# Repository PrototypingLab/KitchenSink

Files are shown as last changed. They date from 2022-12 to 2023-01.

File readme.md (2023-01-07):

# Kitchen Sink

## Kitchen Sink Mini - ESP32-WROOM

### Future Ideas
- Add transistor LED circuit for TX / RX
- Add TVS diode protection circuit

### v1.3 Changelog
- Fixed series capacitor issue on voltage regulators
- Updated power netclass to include RTC battery
- Updated date on silkscreen, added version number

### v1.2 Changelog
- Added solder bridges for selecting IO0 and EN from buttons or (USB-Serial IC and programming header)
- Added 3 additional LEDs on pins designated for shift out
- Moved module closer to edge of board, with space on either side
- Added cutout around module antenna on bottom and top layer
- Added netclass for power traces to be 15 mil
- Updated power traces to 15 mil
- Updated via drill size to be 3 mm
- Updated date on bottom silkscreen

### v1.1 Changelog
- Updated programming header

---------------------

## "Our Programmer"

### v1.1 Changelog
- Added netclass for power traces to be 15 mil
- Updated power traces to 15 mil
- Updated via drill size to be 3 mm
- Updated date on bottom silkscreen

---------------------

## Design Settings
- Trace width: 10 mil
- Power trace width: 15 mil
- Via drill: 3 mm **note units (~ 11.81102 mil)**
- Via annular ring: 10 mil

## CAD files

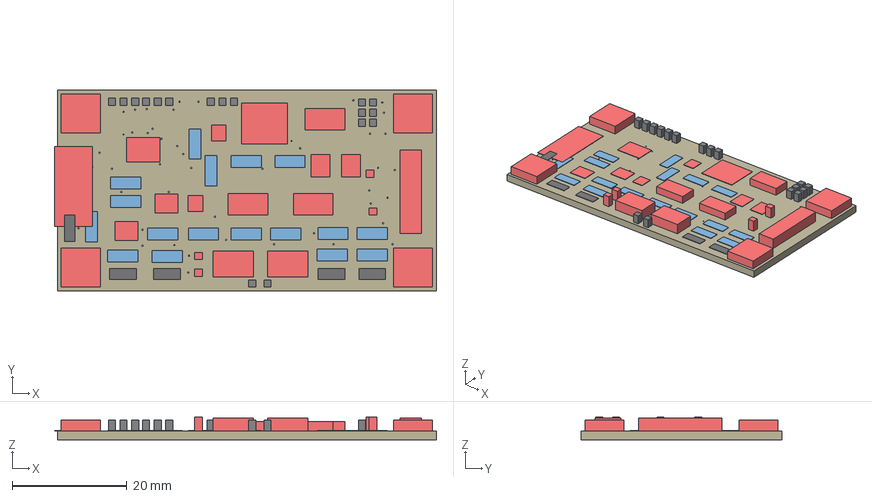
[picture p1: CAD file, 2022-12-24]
our-programmer/esp32_programmer.step
66.7 x 35.0 x 3.99 mm
Board
MOUNT-HOLE3.0 x 4
1206.LED x 5
MOMENTARY-SWITCH-SPST-SMD-5.2MM x 2
TEST-POINT3X5 x 17
CP2102N-A02-GQFN24QFN24_CP2102N_SIL-M
MMBT3904_R1 x 2
AP2111H-3.3TRG1SOT-223_DIO-M
10103592-0001LF-EK
1X03_LONGPADS x 3
1X06_LONGPADS
JUMPER-SMT_2_NC_PASTE_SILK x 4
NPN: BC817 x 4

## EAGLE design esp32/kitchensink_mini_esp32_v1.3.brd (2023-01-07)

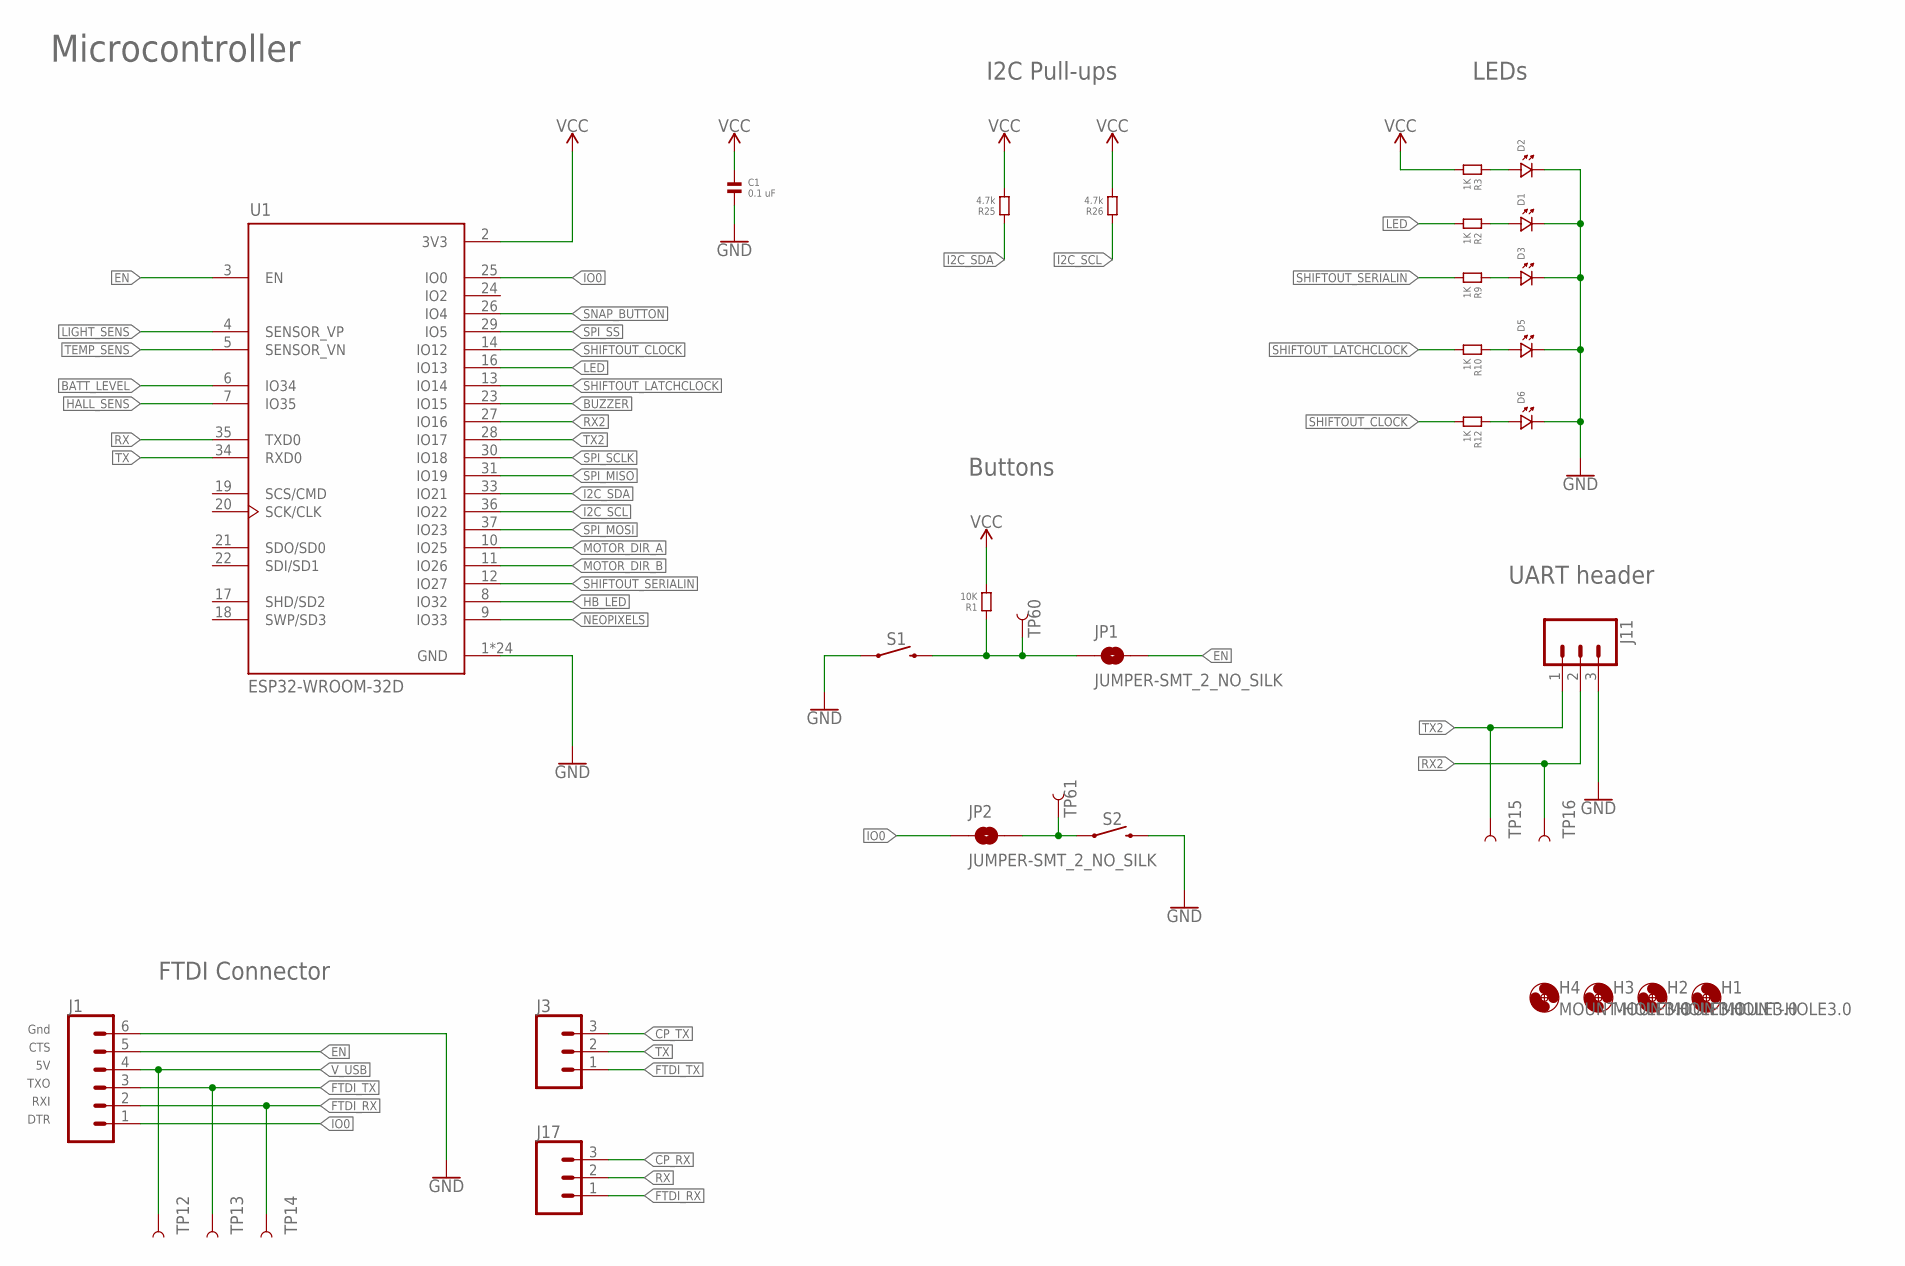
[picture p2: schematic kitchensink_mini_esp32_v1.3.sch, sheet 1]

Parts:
C1: 0.1 uF; 1206
D1, D2, D3, D5, D6: LED.1206; 1206.LED
H1, H2, H3, H4: MOUNT-HOLE3.0; 3,0
J1: CONN_06; 1X06-SMD_RA_MALE_NO_HOLES
J3, J17: CONN_03LONGPADS; 1X03_LONGPADS
J11: CONN_03SMD_RA_MALE; 1X03_SMD_RA_MALE
JP1, JP2: JUMPER-SMT_2_NO_SILK; SMT-JUMPER_2_NO_SILK
R1: 10K; 1206
R2, R3, R9, R10, R12: 1K; 1206
R25, R26: 4.7k; 1206
S1, S2: MOMENTARY-SWITCH-SPST-SMD-5.2MM; TACTILE_SWITCH_SMD_5.2MM
TP12, TP13, TP14, TP15, TP16, TP60, TP61: TEST-POINT3X5; PAD.03X.05
U1: ESP32-WROOM-32D; MODULE_ESP32-WROOM-32D

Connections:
BATT_LEVEL: U1.6 (IO34)
BUZZER: U1.23 (IO15); also elsewhere on the board
CP_RX: J17.3; also elsewhere on the board
CP_TX: J3.3; also elsewhere on the board
EN: J1.5, JP1.2, U1.3 (EN); also elsewhere on the board
FTDI_RX: J1.2, J17.1, TP14.P$1
FTDI_TX: J1.3, J3.1, TP13.P$1
GND: D1.P$2 (2), D2.P$2 (2), D3.P$2 (2), D5.P$2 (2), D6.P$2 (2), J1.6, J11.3, S1.1, U1.1 (GND), U1.15 (GND), U1.38 (GND), U1.39_1 (GND), U1.39_2 (GND), U1.39_3 (GND), U1.39_4 (GND), U1.39_5 (GND), U1.39_6 (GND), U1.39_7 (GND), U1.39_8 (GND), U1.39_9 (GND), U1.39_10 (GND), U1.39_11 (GND), U1.39_12 (GND), U1.39_13 (GND), U1.39_14 (GND), U1.39_15 (GND), U1.39_16 (GND), U1.39_17 (GND), U1.39_18 (GND), U1.39_19 (GND), U1.39_20 (GND), U1.39_21 (GND); also elsewhere on the board
HALL_SENS: U1.7 (IO35)
HB_LED: U1.8 (IO32)
I2C_SCL: R26.1, U1.36 (IO22); also elsewhere on the board
I2C_SDA: R25.1, U1.33 (IO21); also elsewhere on the board
IO0: J1.1, JP2.1, U1.25 (IO0); also elsewhere on the board
LED: R2.2, U1.16 (IO13)
LIGHT_SENS: U1.4 (SENSOR_VP); also elsewhere on the board
MOTOR_DIR_A: U1.10 (IO25)
MOTOR_DIR_B: U1.11 (IO26)
unnamed: C1.2, S2.3 (2)
unnamed: D3.P$1 (1), R9.1
unnamed: D1.P$1 (1), R2.1
unnamed: D5.P$1 (1), R10.1
unnamed: D2.P$1 (1), R3.1
unnamed: D6.P$1 (1), R12.1
NEOPIXELS: U1.9 (IO33); also elsewhere on the board
PRE_EN: JP1.1, R1.1, S1.3 (2), TP60.P$1
PRE_IO0: JP2.2, S2.1, TP61.P$1
RX: J17.2, U1.35 (TXD0)
RX2: J11.2, TP16.P$1, U1.27 (IO16)
SHIFTOUT_CLOCK: R12.2, U1.14 (IO12)
SHIFTOUT_LATCHCLOCK: R10.2, U1.13 (IO14)
SHIFTOUT_SERIALIN: R9.2, U1.12 (IO27)
SNAP_BUTTON: U1.26 (IO4); also elsewhere on the board
SPI_MISO: U1.31 (IO19); also elsewhere on the board
SPI_MOSI: U1.37 (IO23); also elsewhere on the board
SPI_SCLK: U1.30 (IO18); also elsewhere on the board
SPI_SS: U1.29 (IO5); also elsewhere on the board
TEMP_SENS: U1.5 (SENSOR_VN); also elsewhere on the board
TX: J3.2, U1.34 (RXD0)
TX2: J11.1, TP15.P$1, U1.28 (IO17)
VCC: R1.2, R3.2, R25.2, R26.2, U1.2 (3V3); also elsewhere on the board
V_USB: J1.4, TP12.P$1; also elsewhere on the board

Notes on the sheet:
Microcontroller
FTDI Connector
I2C Pull-ups
UART header
LEDs
Buttons
Gnd
CTS
TXO
RXI
DTR

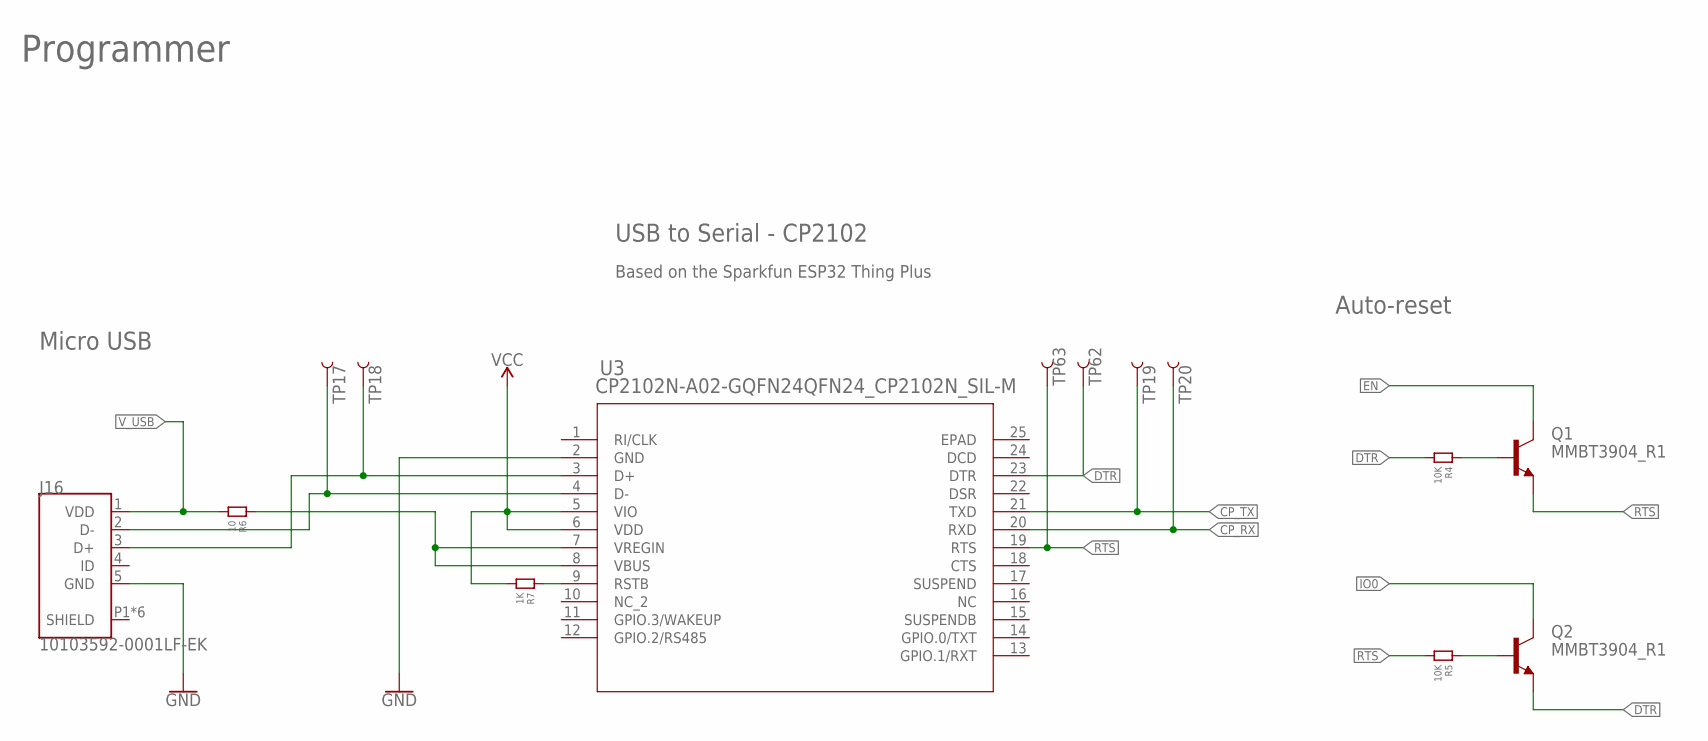
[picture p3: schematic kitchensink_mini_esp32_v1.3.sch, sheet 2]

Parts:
J16: 10103592-0001LF-EK; AMPHENOL_10103592-0001LF
Q1, Q2: MMBT3904_R1; SOT23
R4, R5: 10K; 1206
R6: 10; 1206
R7: 1K; 1206
TP17, TP18, TP19, TP20, TP62, TP63: TEST-POINT3X5; PAD.03X.05
U3: CP2102N-A02-GQFN24QFN24_CP2102N_SIL-M; QFN24_CP2102N_SIL-M

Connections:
CP_RX: TP20.P$1, U3.20 (RXD); also elsewhere on the board
CP_TX: TP19.P$1, U3.21 (TXD); also elsewhere on the board
DTR: Q2.2 (E), R4.2, TP62.P$1, U3.23 (DTR)
EN: Q1.3 (C); also elsewhere on the board
GND: J16.5 (GND), U3.2 (GND); also elsewhere on the board
IO0: Q2.3 (C); also elsewhere on the board
unnamed: R6.1, U3.7 (VREGIN), U3.8 (VBUS)
unnamed: J16.3 (D+), TP18.P$1, U3.3 (D+)
unnamed: J16.2 (D-), TP17.P$1, U3.4 (D-)
unnamed: Q1.1 (B), R4.1
unnamed: Q2.1 (B), R5.1
unnamed: R7.1, U3.9 (RSTB)
RTS: Q1.2 (E), R5.2, TP63.P$1, U3.19 (RTS)
SHIELD: J16.P1 (SHIELD), J16.P2 (SHIELD), J16.P3 (SHIELD), J16.P4 (SHIELD), J16.P5 (SHIELD), J16.P6 (SHIELD)
VCC: R7.2, U3.5 (VIO), U3.6 (VDD); also elsewhere on the board
V_USB: J16.1 (VDD), R6.2; also elsewhere on the board

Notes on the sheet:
Programmer
USB to Serial - CP2102
Auto-reset
Micro USB
Based on the Sparkfun ESP32 Thing Plus

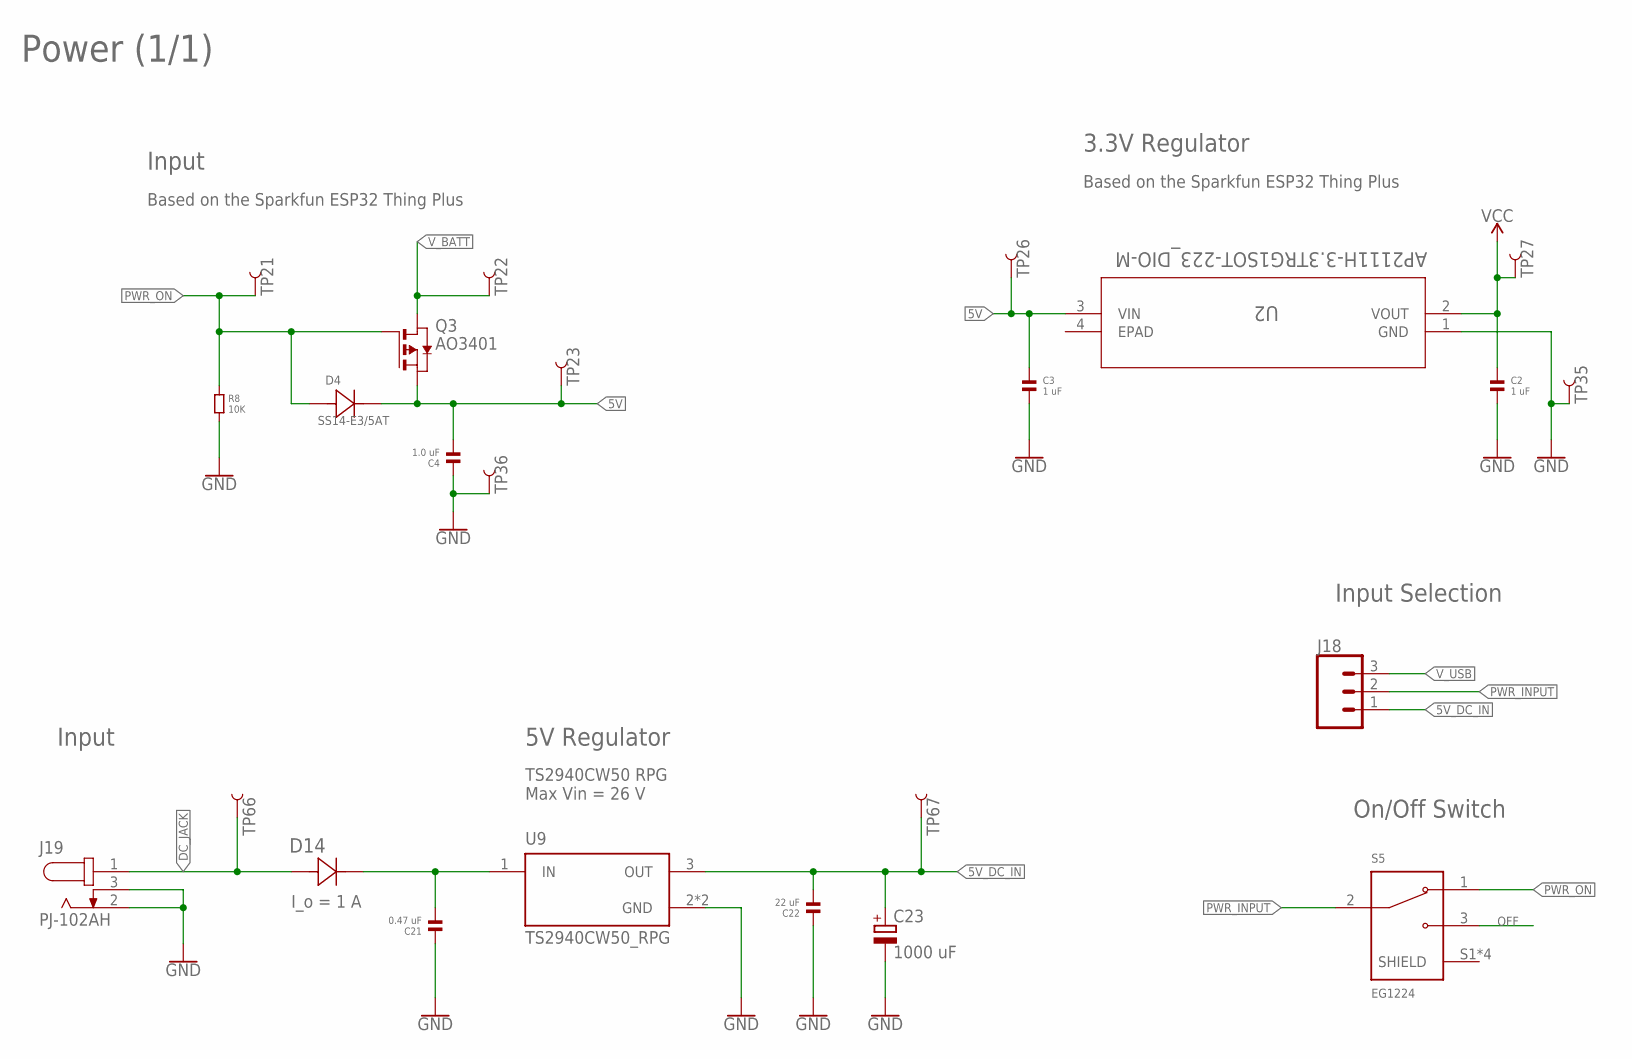
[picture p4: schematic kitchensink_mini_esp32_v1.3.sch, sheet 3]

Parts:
C2, C3: 1 uF; 1206
C4: 1.0 uF; 1206
C21: 0.47 uF; 1206
C22: 22 uF; 1206
C23: 1000 uF; 140CLH-1010
D4: SS14-E3/5AT; DIODE_DO214AC
D14: RS1BB-13-FSMA_DIO-M; SMA_DIO-M
J18: CONN_03; 1X03
J19: PJ-102AH; CUI_PJ-102AH
Q3: AO3401; SOT23
R8: 10K; 1206
S5: EG1224; SW_EG1224
TP21, TP22, TP23, TP26, TP27, TP35, TP36, TP66, TP67: TEST-POINT3X5; PAD.03X.05
U2: AP2111H-3.3TRG1SOT-223_DIO-M; SOT-223_DIO-M
U9: TS2940CW50_RPG; VREG_TS2940CW50_RPG

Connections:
5V: C3.1, C4.2, D4.1, Q3.2 (S), TP23.P$1, TP26.P$1, U2.3 (VIN); also elsewhere on the board
5V_DC_IN: C22.2, C23.+, J18.1, TP67.P$1, U9.3 (OUT)
DC_JACK: D14.2, J19.1, TP66.P$1
GND: C2.2, C3.2, C4.1, C21.1, C22.1, C23.-, J19.2, J19.3, R8.2, TP35.P$1, TP36.P$1, U2.1 (GND), U9.2 (GND), U9.4 (GND); also elsewhere on the board
unnamed: C21.2, D14.1, U9.1 (IN)
OFF: S5.3
PWR_INPUT: J18.2, S5.2
PWR_ON: D4.2, Q3.1 (G), R8.1, S5.1, TP21.P$1
VCC: C2.1, TP27.P$1, U2.2 (VOUT); also elsewhere on the board
V_BATT: Q3.3 (D), TP22.P$1
V_USB: J18.3; also elsewhere on the board

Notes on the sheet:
Power (1/1)
Input
Based on the Sparkfun ESP32 Thing Plus
3.3V Regulator
Input Selection
5V Regulator
TS2940CW50 RPG Max Vin = 26 V
I_o = 1 A
On/Off Switch

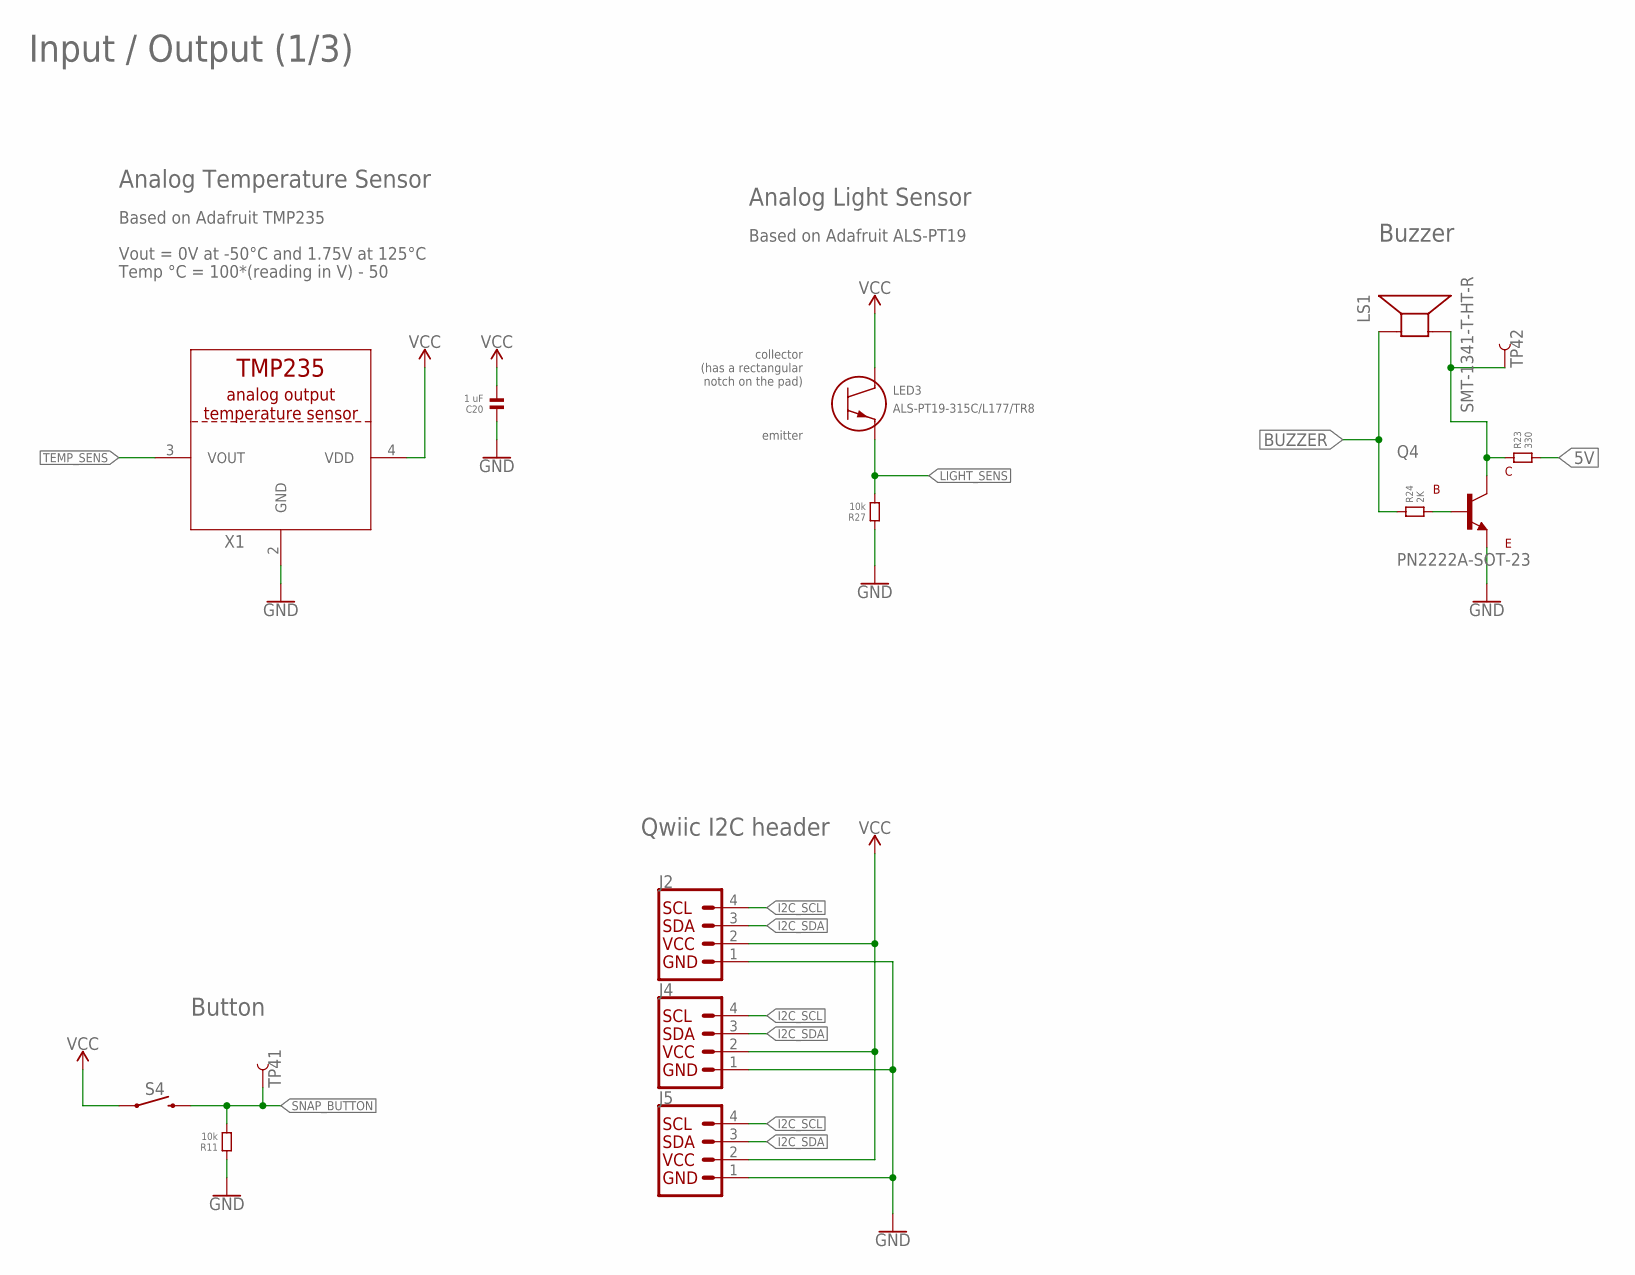
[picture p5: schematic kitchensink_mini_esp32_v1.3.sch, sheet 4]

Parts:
C20: 1 uF; 1206
J2, J4, J5: QWIIC_CONNECTORJS-1MM; 1X04_1MM_RA
LED3: ALS-PT19-315C/L177/TR8; LED_77/TR8_EVE
LS1: SMT-1341-T-HT-R; XDCR_SMT-1341-T-HT-R
Q4: PN2222A-SOT-23
R11, R27: 10k; 1206
R23: 330; 1206
R24: 2K; 1206
S4: MOMENTARY-SWITCH-SPST-SMD-5.2MM; TACTILE_SWITCH_SMD_5.2MM
TP41, TP42: TEST-POINT3X5; PAD.03X.05
X1: TMP235_DCKR; SC70-5

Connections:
5V: R23.2; also elsewhere on the board
BUZZER: LS1.P, R24.1; also elsewhere on the board
GND: C20.1, J2.1 (GND), J4.1 (GND), J5.1 (GND), Q4.EMITTER, R11.1, R27.1, X1.2 (GND); also elsewhere on the board
I2C_SCL: J2.4 (SCL), J4.4 (SCL), J5.4 (SCL); also elsewhere on the board
I2C_SDA: J2.3 (SDA), J4.3 (SDA), J5.3 (SDA); also elsewhere on the board
LIGHT_SENS: LED3.2, R27.2; also elsewhere on the board
unnamed: LS1.N, Q4.COLLECTOR, R23.1, TP42.P$1
unnamed: Q4.BASE, R24.2
SNAP_BUTTON: R11.2, S4.3 (2), TP41.P$1; also elsewhere on the board
TEMP_SENS: X1.3 (VOUT); also elsewhere on the board
VCC: C20.2, J2.2 (VCC), J4.2 (VCC), J5.2 (VCC), LED3.1, S4.1, X1.4 (VDD); also elsewhere on the board

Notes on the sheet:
Input / Output (1/3)
Analog Temperature Sensor
Based on Adafruit TMP235
Vout = 0V at -50°C and 1.75V at 125°C
Temp °C = 100*(reading in V) - 50
Analog Light Sensor
collector (has a rectangular notch on the pad)
emitter
Based on Adafruit ALS-PT19
Button
Buzzer
Qwiic I2C header

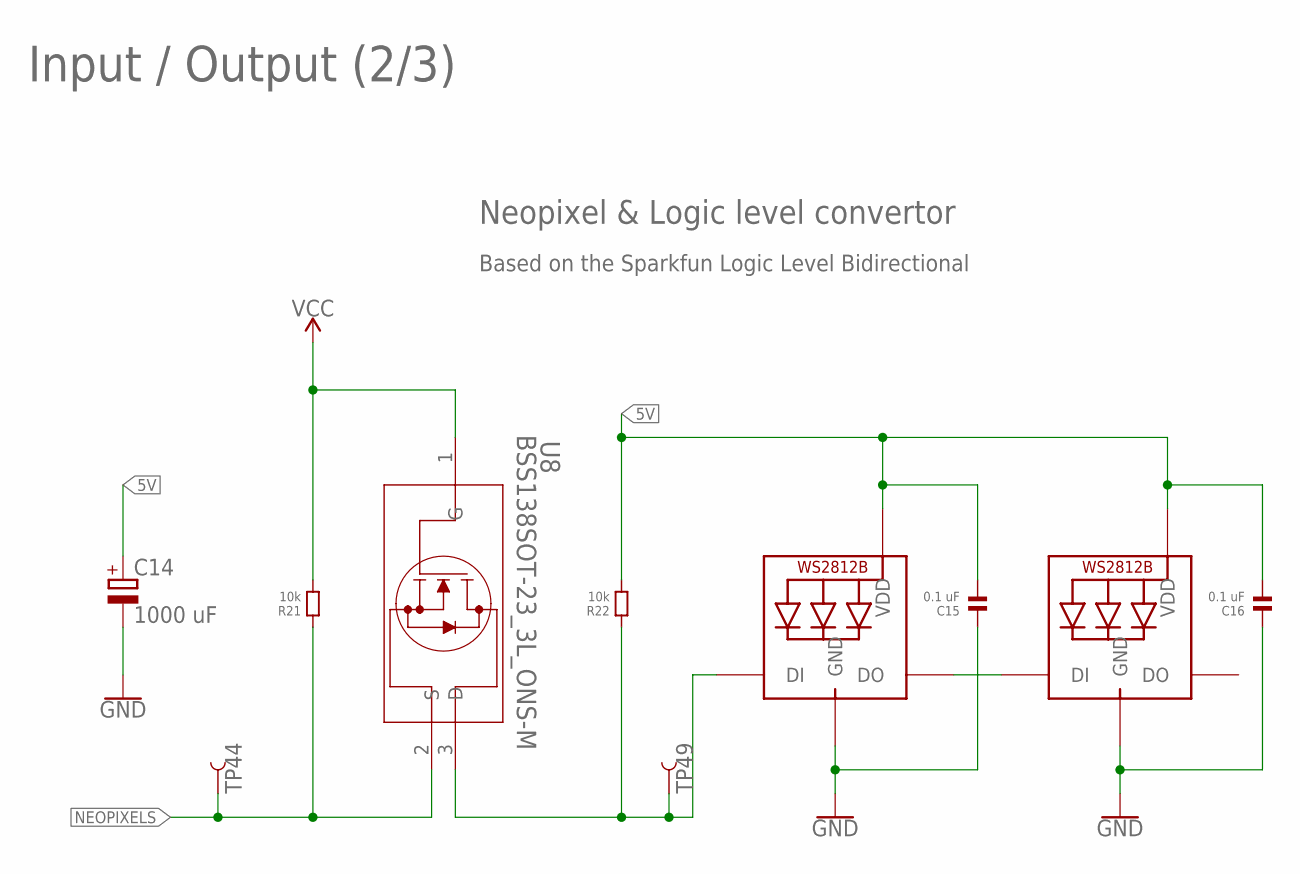
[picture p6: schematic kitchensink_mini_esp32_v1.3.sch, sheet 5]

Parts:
C14: 1000 uF; 140CLH-1010
C15, C16: 0.1 uF; 1206
LED1, LED2: WS2812B5050; WS2812B
R21, R22: 10k; 1206
TP44, TP49: TEST-POINT3X5; PAD.03X.05
U8: BSS138SOT-23_3L_ONS-M; SOT-23_3L_ONS-M

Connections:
5V: C14.+, C15.2, C16.2, LED1.1-VDD (VDD), LED2.1-VDD (VDD), R22.2; also elsewhere on the board
GND: C14.-, C15.1, C16.1, LED1.3-GND (GND), LED2.3-GND (GND); also elsewhere on the board
unnamed: LED1.4-DIN (DI), R22.1, TP49.P$1, U8.3 (D)
unnamed: LED1.2-DOUT (DO), LED2.4-DIN (DI)
NEOPIXELS: R21.1, TP44.P$1, U8.2 (S); also elsewhere on the board
VCC: R21.2, U8.1 (G); also elsewhere on the board

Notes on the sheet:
Input / Output (2/3)
Neopixel & Logic level convertor
Based on the Sparkfun Logic Level Bidirectional

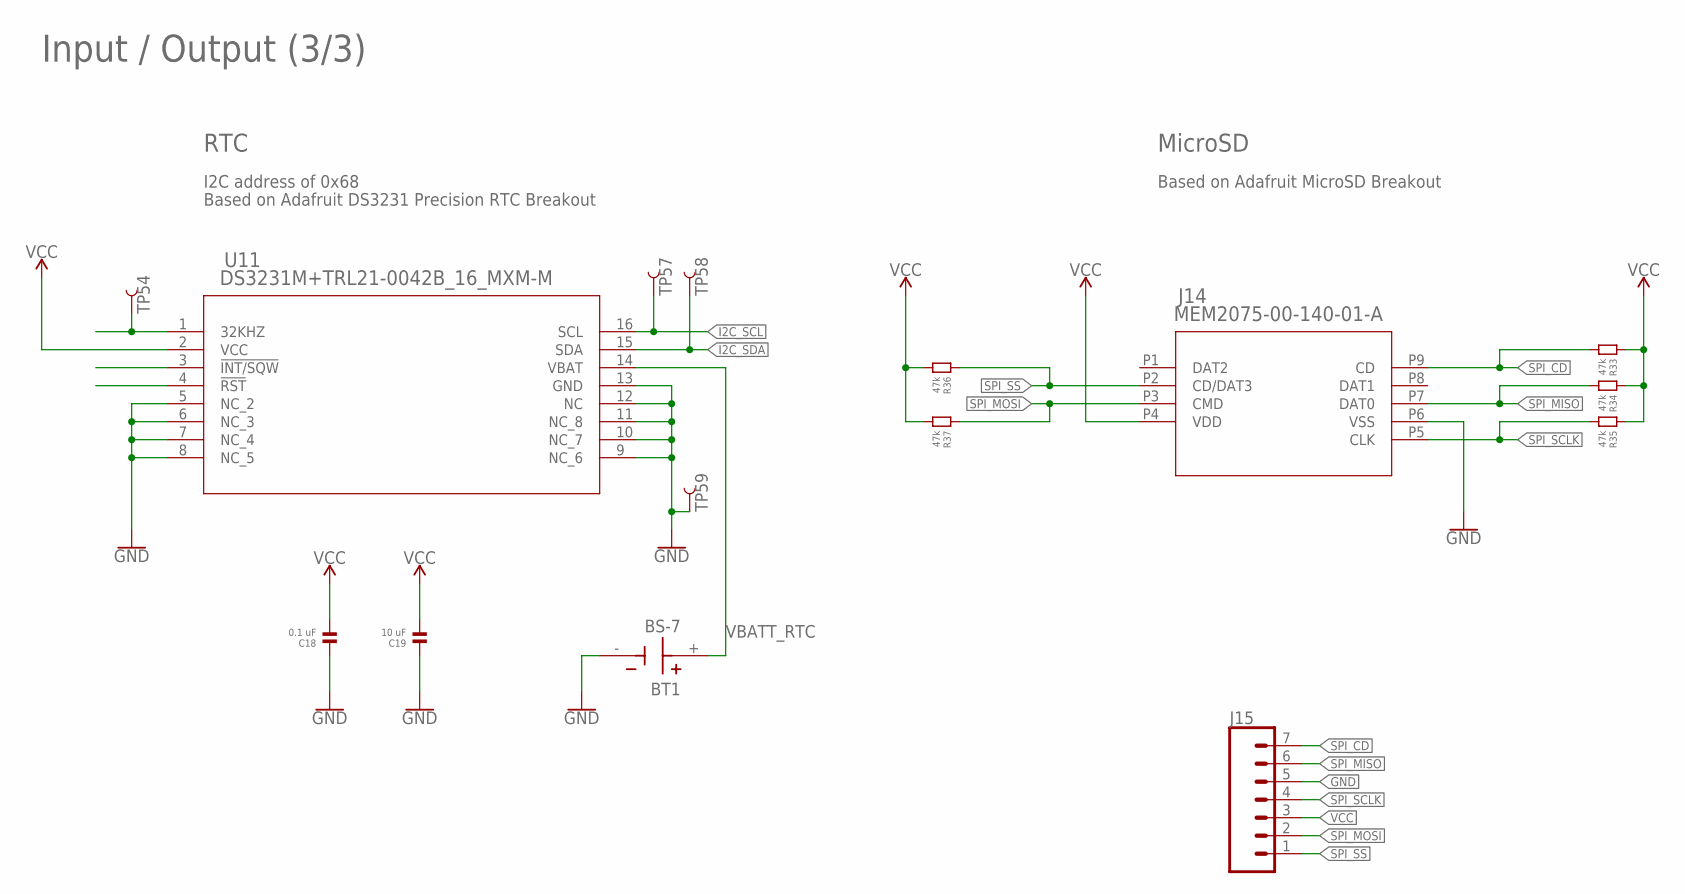
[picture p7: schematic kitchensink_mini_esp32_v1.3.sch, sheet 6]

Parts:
BT1: BS-7; BAT_BS-7
C18: 0.1 uF; 1206
C19: 10 uF; 1206
J14: MEM2075-00-140-01-A; MEM2075-00-140-01-A_GCT
J15: CONN_07LONGPADS; 1X07_LONGPADS
R33, R34, R35, R36, R37: 47k; 1206
TP54, TP57, TP58, TP59: TEST-POINT3X5; PAD.03X.05
U11: DS3231M+TRL21-0042B_16_MXM-M; 21-0042B_16_MXM-M

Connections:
GND: BT1.-, C18.1, C19.1, J14.P6 (VSS), J15.5, TP59.P$1, U11.5 (NC_2), U11.6 (NC_3), U11.7 (NC_4), U11.8 (NC_5), U11.9 (NC_6), U11.10 (NC_7), U11.11 (NC_8), U11.12 (NC), U11.13 (GND); also elsewhere on the board
I2C_SCL: TP57.P$1, U11.16 (SCL); also elsewhere on the board
I2C_SDA: TP58.P$1, U11.15 (SDA); also elsewhere on the board
unnamed: TP54.P$1, U11.1 (32KHZ)
SPI_CD: J14.P9 (CD), J15.7, R33.2
SPI_MISO: J14.P7 (DAT0), J15.6, R34.2; also elsewhere on the board
SPI_MOSI: J14.P3 (CMD), J15.2, R37.1; also elsewhere on the board
SPI_SCLK: J14.P5 (CLK), J15.4, R35.2; also elsewhere on the board
SPI_SS: J14.P2 (CD/DAT3), J15.1, R36.1; also elsewhere on the board
VBATT_RTC: BT1.+, U11.14 (VBAT)
VCC: C18.2, C19.2, J14.P4 (VDD), J15.3, R33.1, R34.1, R35.1, R36.2, R37.2, U11.2 (VCC); also elsewhere on the board

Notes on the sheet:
Input / Output (3/3)
RTC
I2C address of 0x68
Based on Adafruit DS3231 Precision RTC Breakout
MicroSD
Based on Adafruit MicroSD Breakout

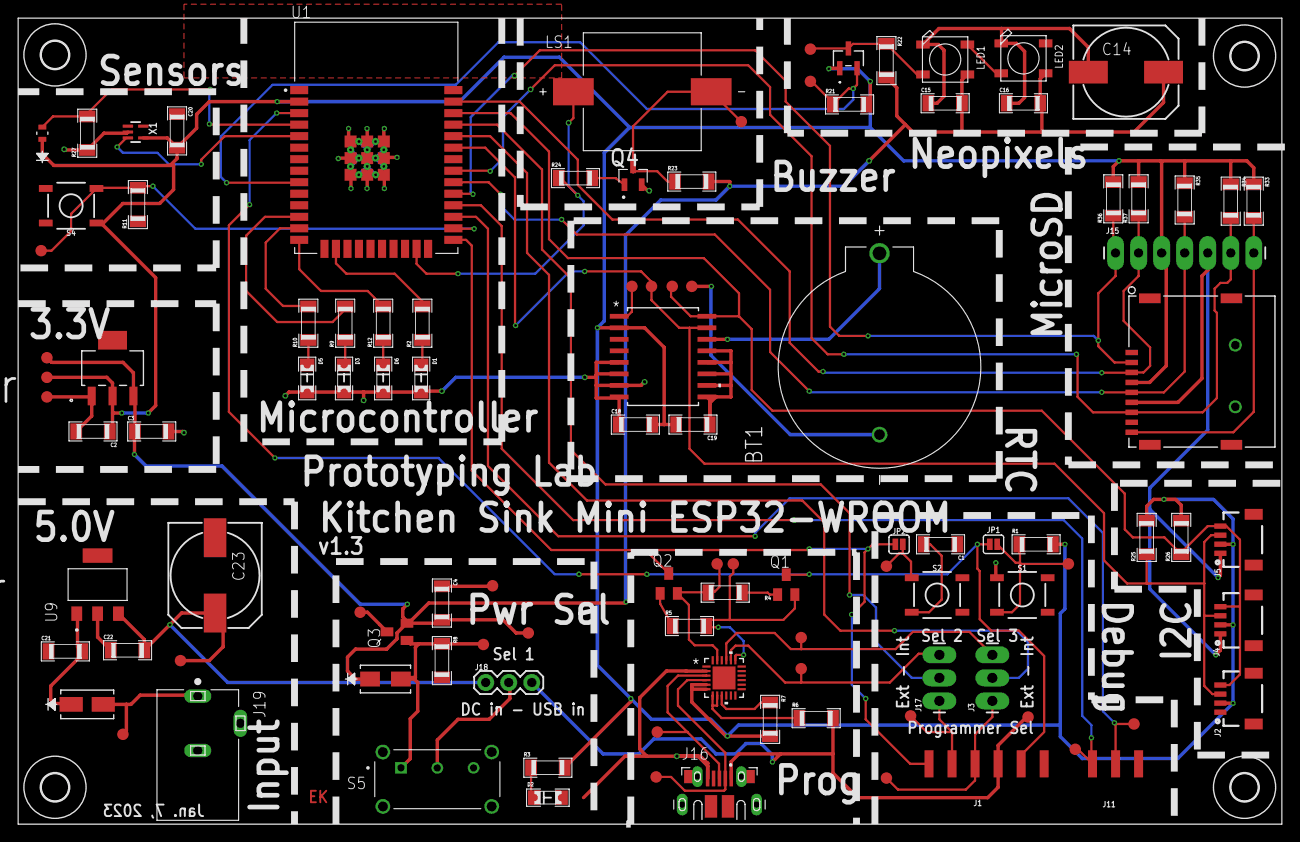
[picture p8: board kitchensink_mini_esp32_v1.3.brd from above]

Board: 2 copper layers, 139.4 x 88.9 mm, 112 parts (0 on the bottom side), 59 nets.

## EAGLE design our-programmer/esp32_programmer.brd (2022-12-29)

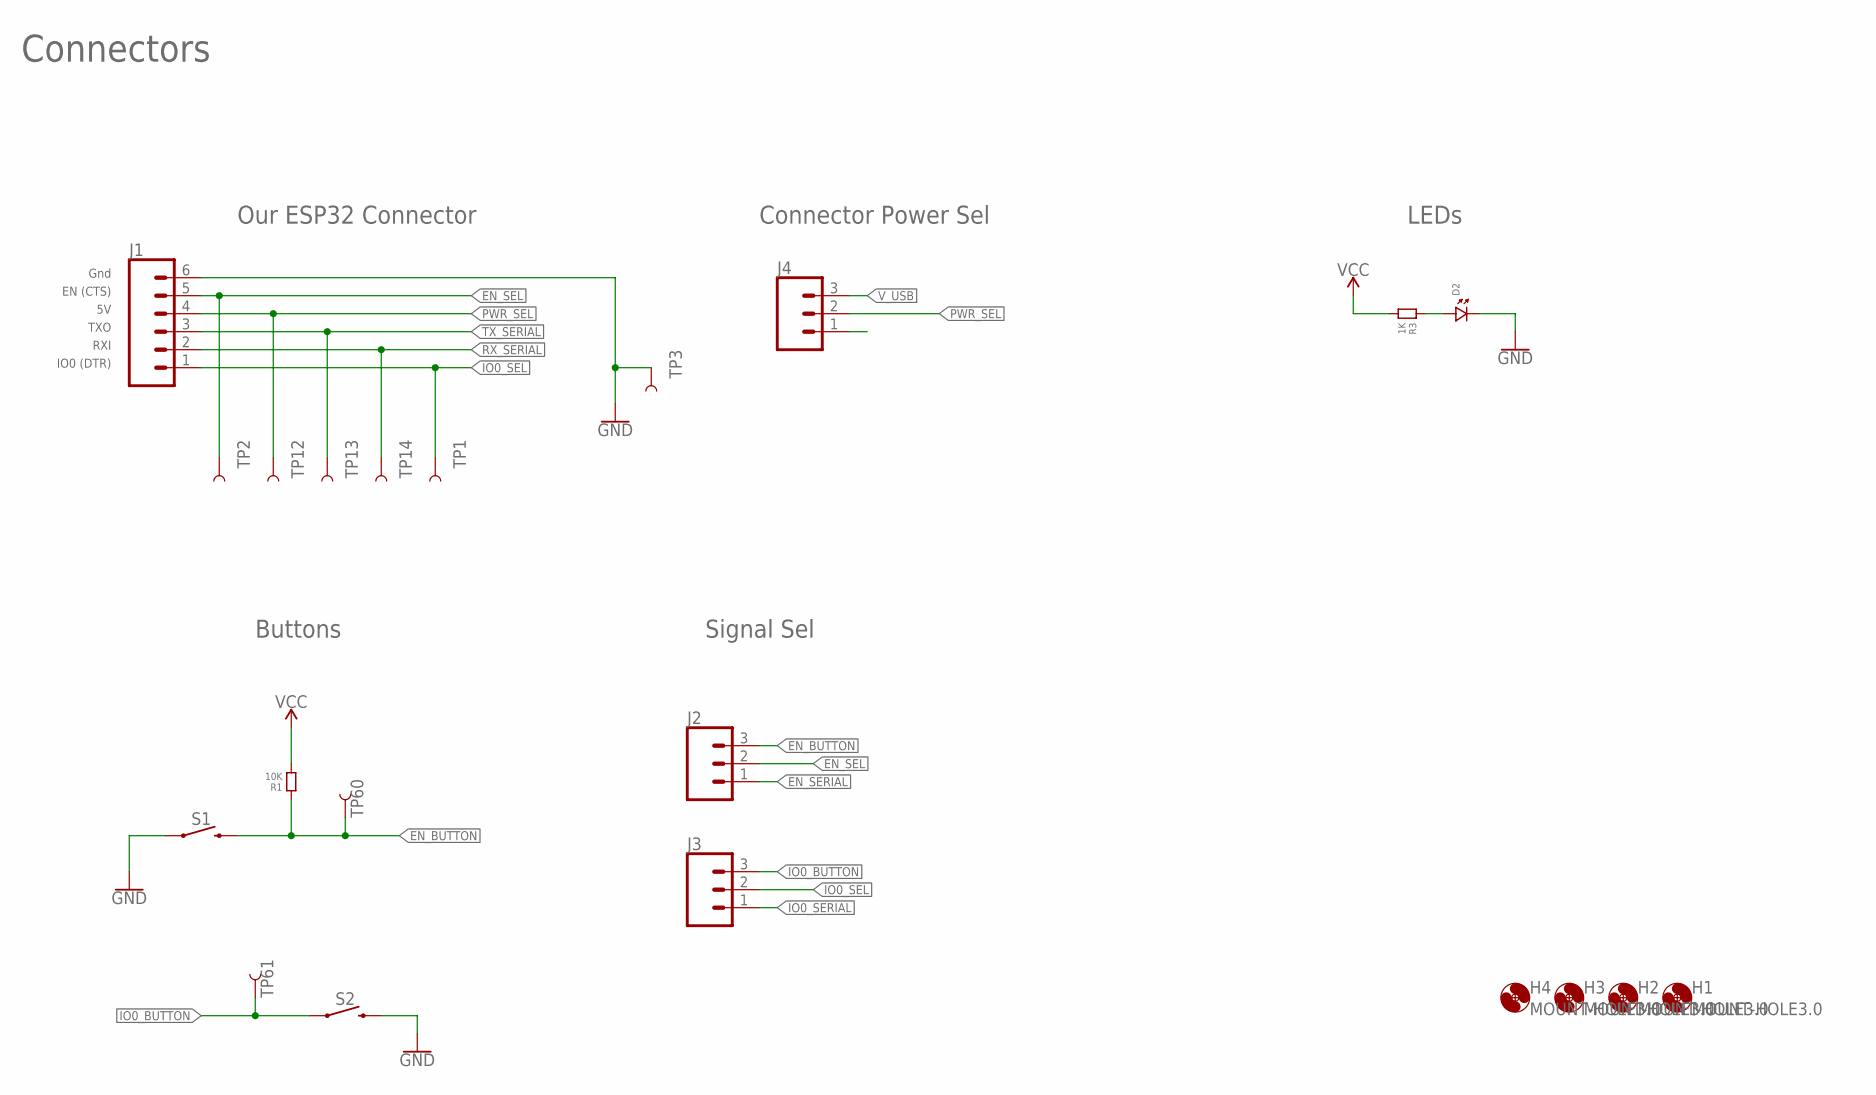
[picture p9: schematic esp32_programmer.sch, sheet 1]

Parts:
D2: LED.1206; 1206.LED
H1, H2, H3, H4: MOUNT-HOLE3.0; 3,0
J1: CONN_06LONGPADS; 1X06_LONGPADS
J2, J3, J4: CONN_03LONGPADS; 1X03_LONGPADS
R1: 10K; 1206
R3: 1K; 1206
S1, S2: MOMENTARY-SWITCH-SPST-SMD-5.2MM; TACTILE_SWITCH_SMD_5.2MM
TP1, TP2, TP3, TP12, TP13, TP14, TP60, TP61: TEST-POINT3X5; PAD.03X.05

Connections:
EN_BUTTON: J2.3, R1.1, S1.3 (2), TP60.P$1
EN_SEL: J1.5, J2.2, TP2.P$1
EN_SERIAL: J2.1; also elsewhere on the board
GND: D2.P$2 (2), J1.6, S1.1, S2.3 (2), TP3.P$1; also elsewhere on the board
IO0_BUTTON: J3.3, S2.1, TP61.P$1
IO0_SEL: J1.1, J3.2, TP1.P$1
IO0_SERIAL: J3.1; also elsewhere on the board
unnamed: D2.P$1 (1), R3.1
PWR_SEL: J1.4, J4.2, TP12.P$1
RX_SERIAL: J1.2, TP14.P$1; also elsewhere on the board
TX_SERIAL: J1.3, TP13.P$1; also elsewhere on the board
VCC: R1.2, R3.2; also elsewhere on the board
V_USB: J4.3; also elsewhere on the board

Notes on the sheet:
Our ESP32 Connector
LEDs
Buttons
Gnd
EN (CTS)
TXO
RXI
IO0 (DTR)
Connectors
Connector Power Sel
Signal Sel

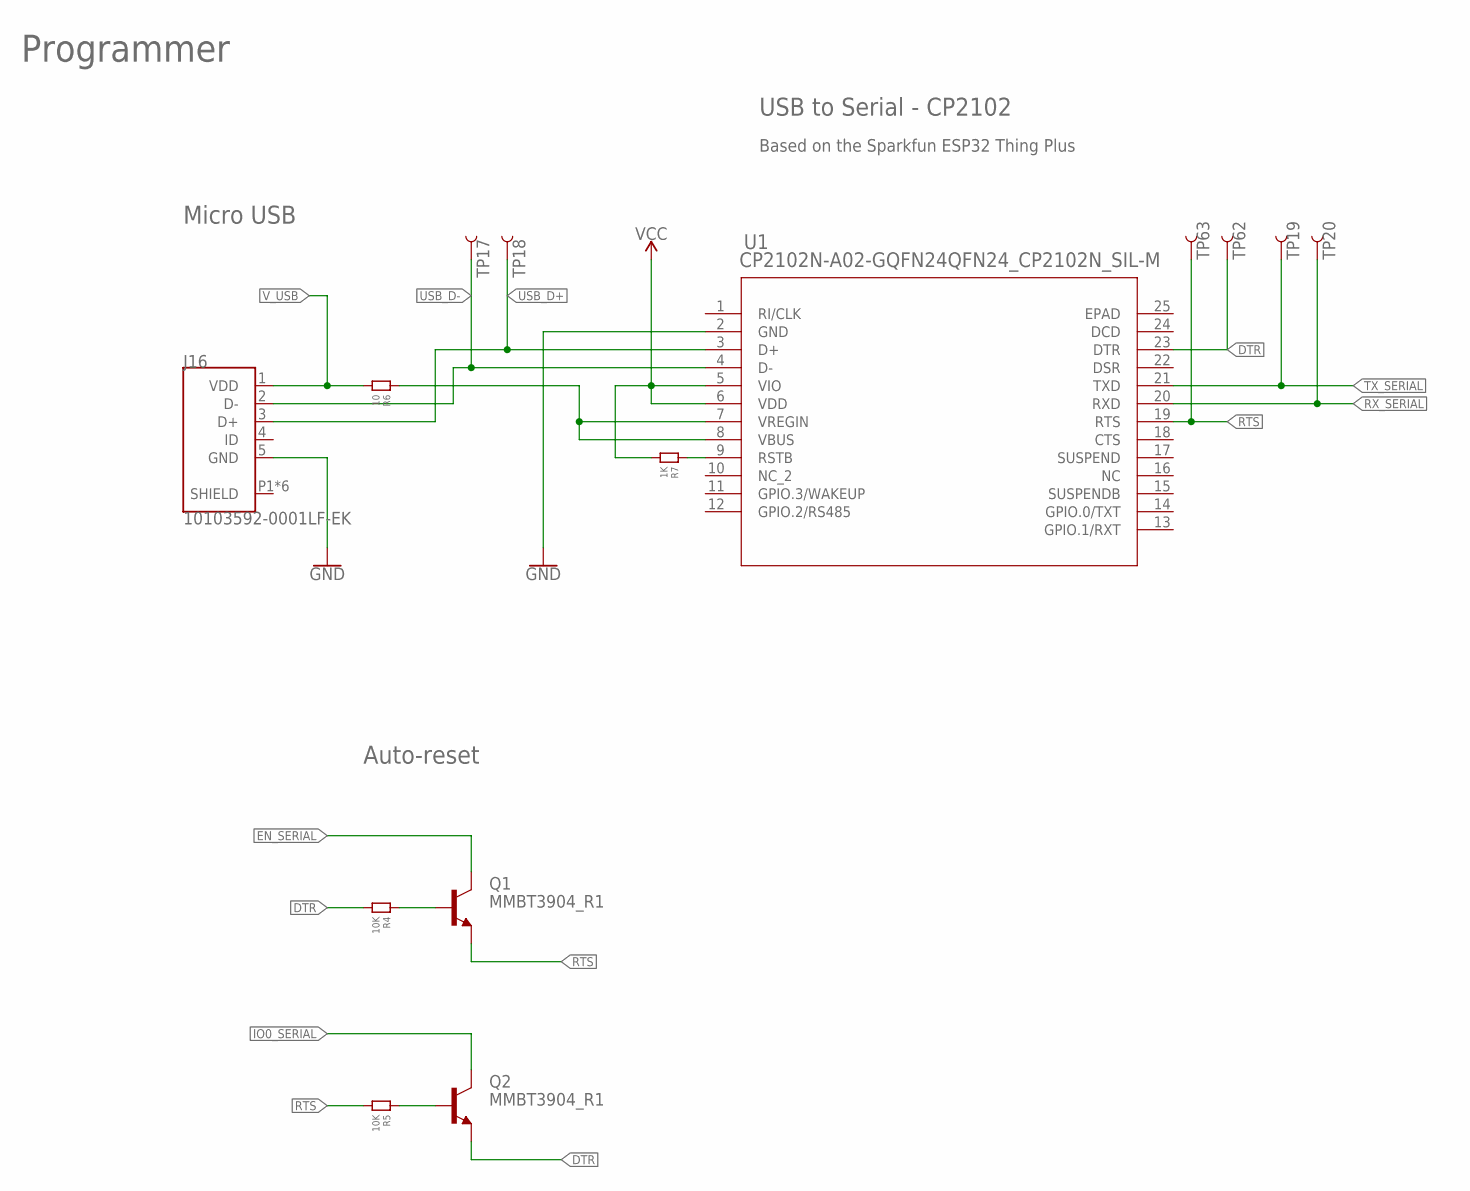
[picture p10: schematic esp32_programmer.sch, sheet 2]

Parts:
J16: 10103592-0001LF-EK; AMPHENOL_10103592-0001LF
Q1, Q2: MMBT3904_R1; SOT23
R4, R5: 10K; 1206
R6: 10; 1206
R7: 1K; 1206
TP17, TP18, TP19, TP20, TP62, TP63: TEST-POINT3X5; PAD.03X.05
U1: CP2102N-A02-GQFN24QFN24_CP2102N_SIL-M; QFN24_CP2102N_SIL-M

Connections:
DTR: Q2.2 (E), R4.2, TP62.P$1, U1.23 (DTR)
EN_SERIAL: Q1.3 (C); also elsewhere on the board
GND: J16.5 (GND), U1.2 (GND); also elsewhere on the board
IO0_SERIAL: Q2.3 (C); also elsewhere on the board
unnamed: R6.1, U1.7 (VREGIN), U1.8 (VBUS)
unnamed: Q1.1 (B), R4.1
unnamed: Q2.1 (B), R5.1
unnamed: R7.1, U1.9 (RSTB)
RTS: Q1.2 (E), R5.2, TP63.P$1, U1.19 (RTS)
RX_SERIAL: TP20.P$1, U1.20 (RXD); also elsewhere on the board
SHIELD: J16.P1 (SHIELD), J16.P2 (SHIELD), J16.P3 (SHIELD), J16.P4 (SHIELD), J16.P5 (SHIELD), J16.P6 (SHIELD)
TX_SERIAL: TP19.P$1, U1.21 (TXD); also elsewhere on the board
USB_D+: J16.3 (D+), TP18.P$1, U1.3 (D+); also elsewhere on the board
USB_D-: J16.2 (D-), TP17.P$1, U1.4 (D-); also elsewhere on the board
VCC: R7.2, U1.5 (VIO), U1.6 (VDD); also elsewhere on the board
V_USB: J16.1 (VDD), R6.2; also elsewhere on the board

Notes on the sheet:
Programmer
USB to Serial - CP2102
Auto-reset
Micro USB
Based on the Sparkfun ESP32 Thing Plus

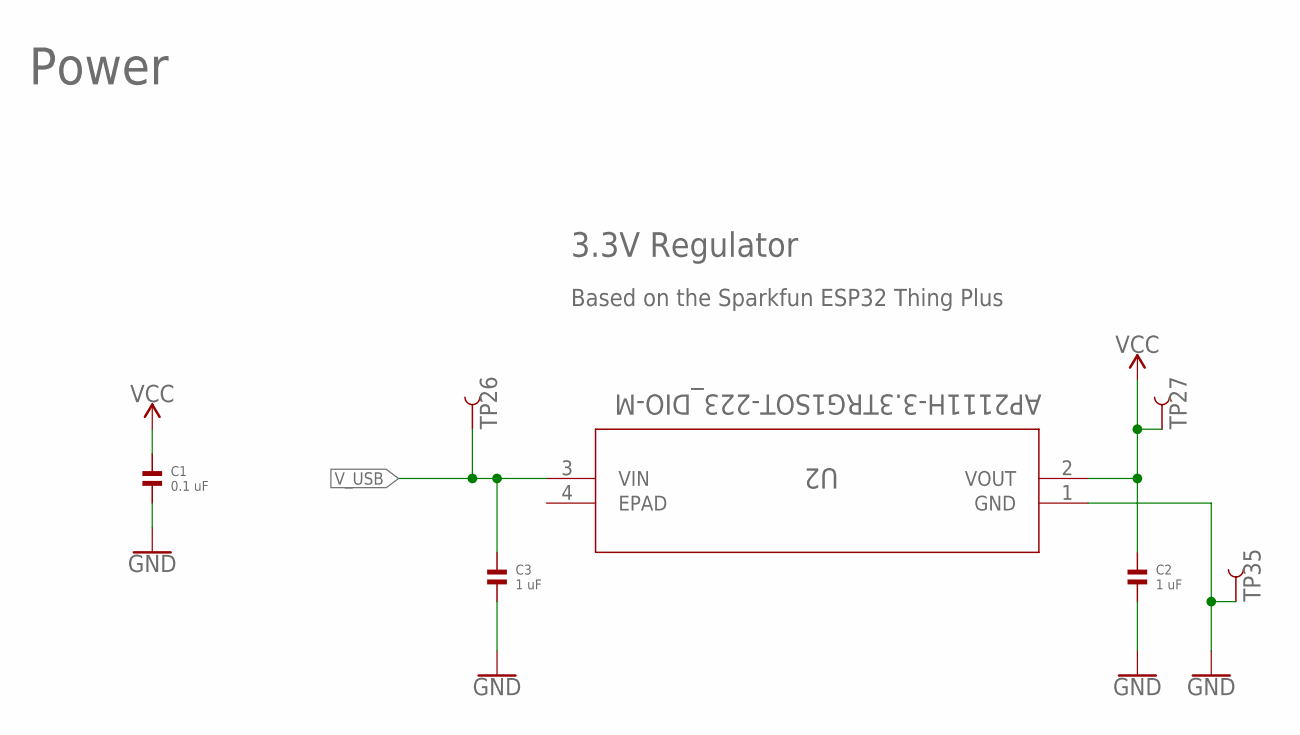
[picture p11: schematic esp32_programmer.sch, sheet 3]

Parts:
C1: 0.1 uF; 1206
C2, C3: 1 uF; 1206
TP26, TP27, TP35: TEST-POINT3X5; PAD.03X.05
U2: AP2111H-3.3TRG1SOT-223_DIO-M; SOT-223_DIO-M

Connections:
GND: C1.2, C2.2, C3.2, TP35.P$1, U2.1 (GND); also elsewhere on the board
VCC: C1.1, C2.1, TP27.P$1, U2.2 (VOUT); also elsewhere on the board
V_USB: C3.1, TP26.P$1, U2.3 (VIN); also elsewhere on the board

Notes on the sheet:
Power
3.3V Regulator
Based on the Sparkfun ESP32 Thing Plus

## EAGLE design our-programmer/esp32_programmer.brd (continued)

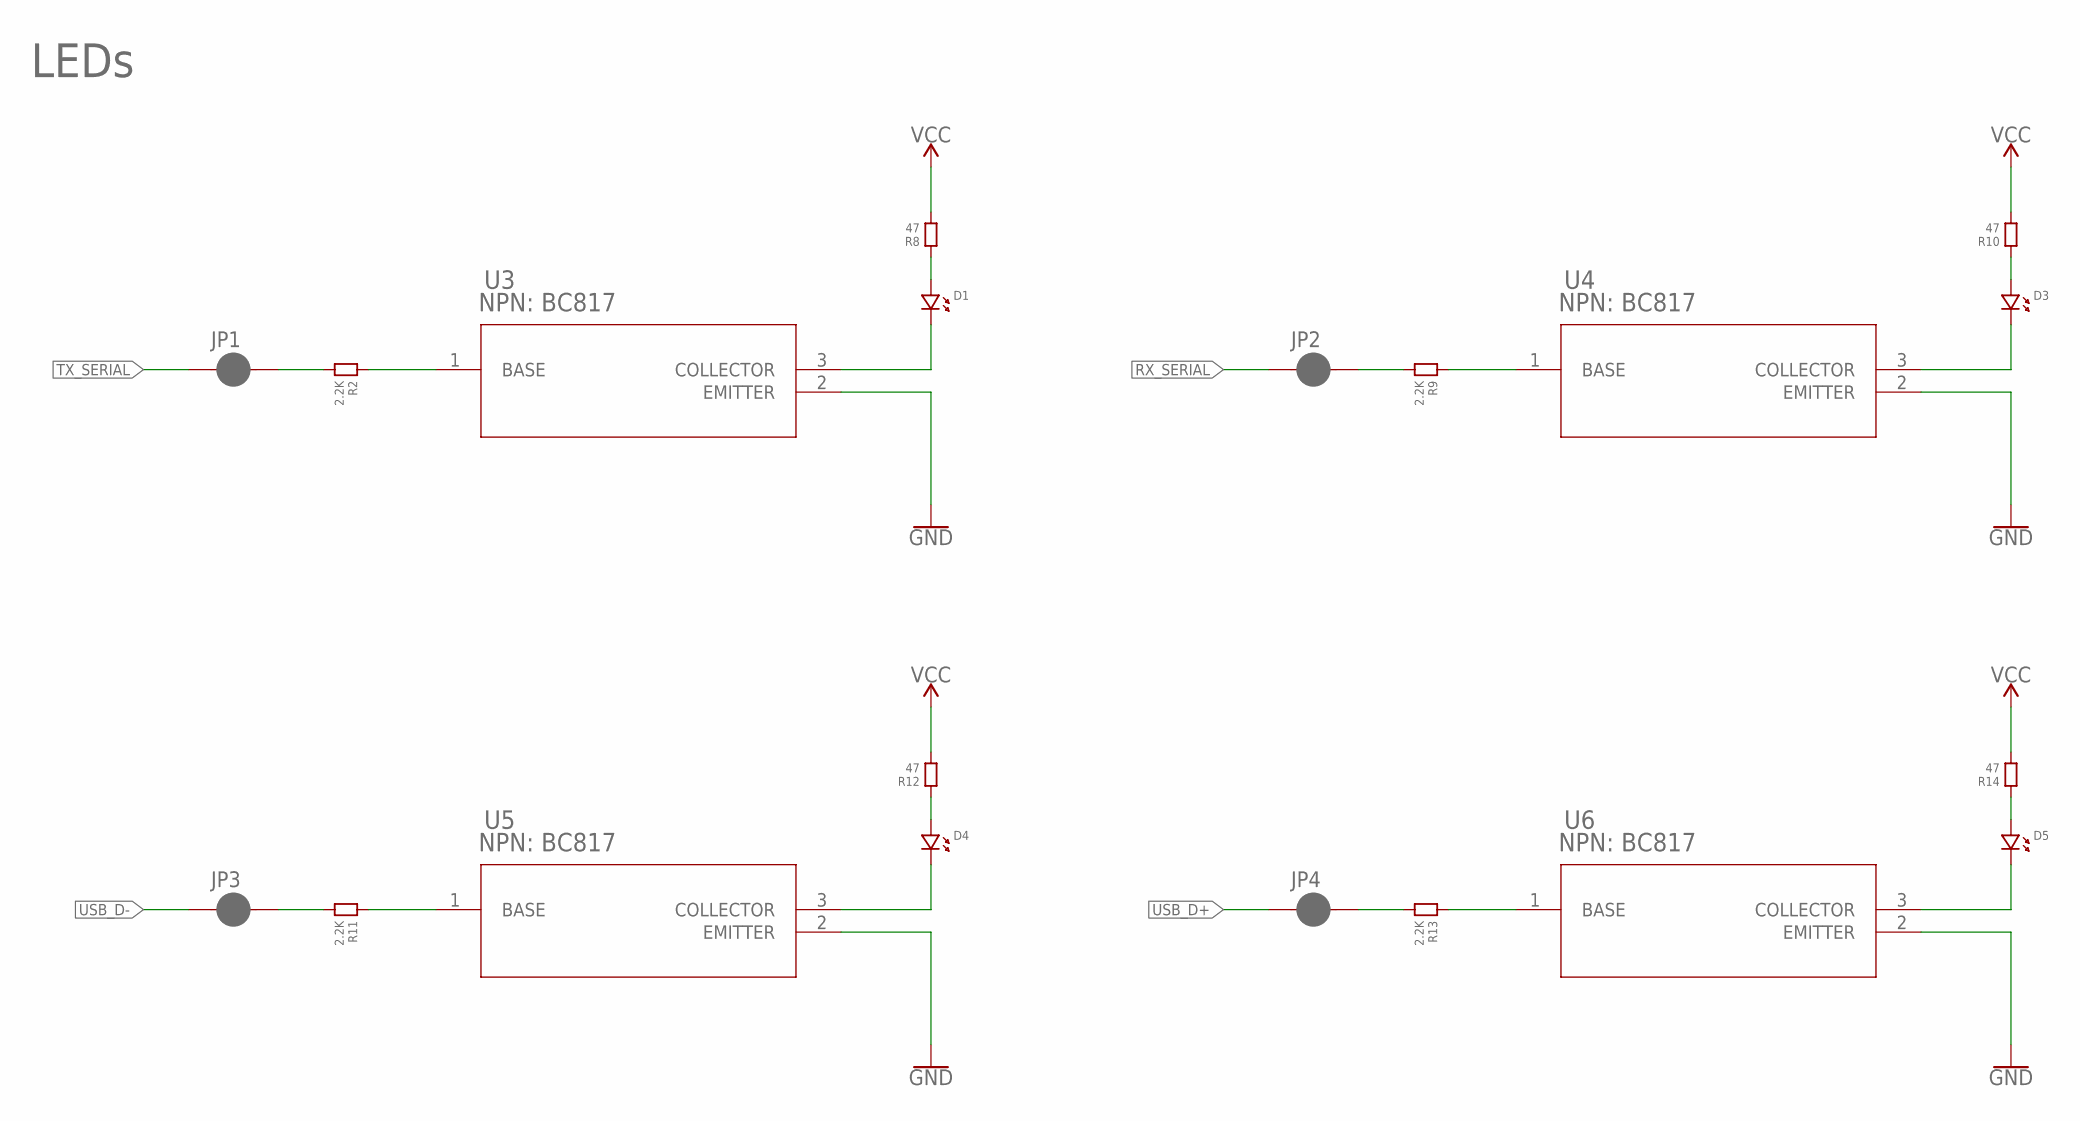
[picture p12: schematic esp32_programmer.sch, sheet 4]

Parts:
D1, D3, D4, D5: LED.1206; 1206.LED
JP1, JP2, JP3, JP4: JUMPER-SMT_2_NC_PASTE_SILK; SMT-JUMPER_2_NC_PASTE_SILK
R2, R9, R11, R13: 2.2K; 1206
R8, R10, R12, R14: 47; 1206
U3, U4, U5, U6: NPN: BC817; SOT-23-3_1P4X3P040_ONS-M

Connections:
BLEP1: D4.P$2 (2), U5.3 (COLLECTOR)
BLEP2: D5.P$2 (2), U6.3 (COLLECTOR)
BLEP3: D1.P$2 (2), U3.3 (COLLECTOR)
BLEP4: D3.P$2 (2), U4.3 (COLLECTOR)
GND: U3.2 (EMITTER), U4.2 (EMITTER), U5.2 (EMITTER), U6.2 (EMITTER); also elsewhere on the board
unnamed: JP1.2, R2.2
unnamed: JP2.2, R9.2
unnamed: R2.1, U3.1 (BASE)
unnamed: D1.P$1 (1), R8.1
unnamed: R9.1, U4.1 (BASE)
unnamed: D3.P$1 (1), R10.1
unnamed: JP3.2, R11.2
unnamed: R11.1, U5.1 (BASE)
unnamed: D4.P$1 (1), R12.1
unnamed: JP4.2, R13.2
unnamed: R13.1, U6.1 (BASE)
unnamed: D5.P$1 (1), R14.1
RX_SERIAL: JP2.1; also elsewhere on the board
TX_SERIAL: JP1.1; also elsewhere on the board
USB_D+: JP4.1; also elsewhere on the board
USB_D-: JP3.1; also elsewhere on the board
VCC: R8.2, R10.2, R12.2, R14.2; also elsewhere on the board

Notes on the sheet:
LEDs

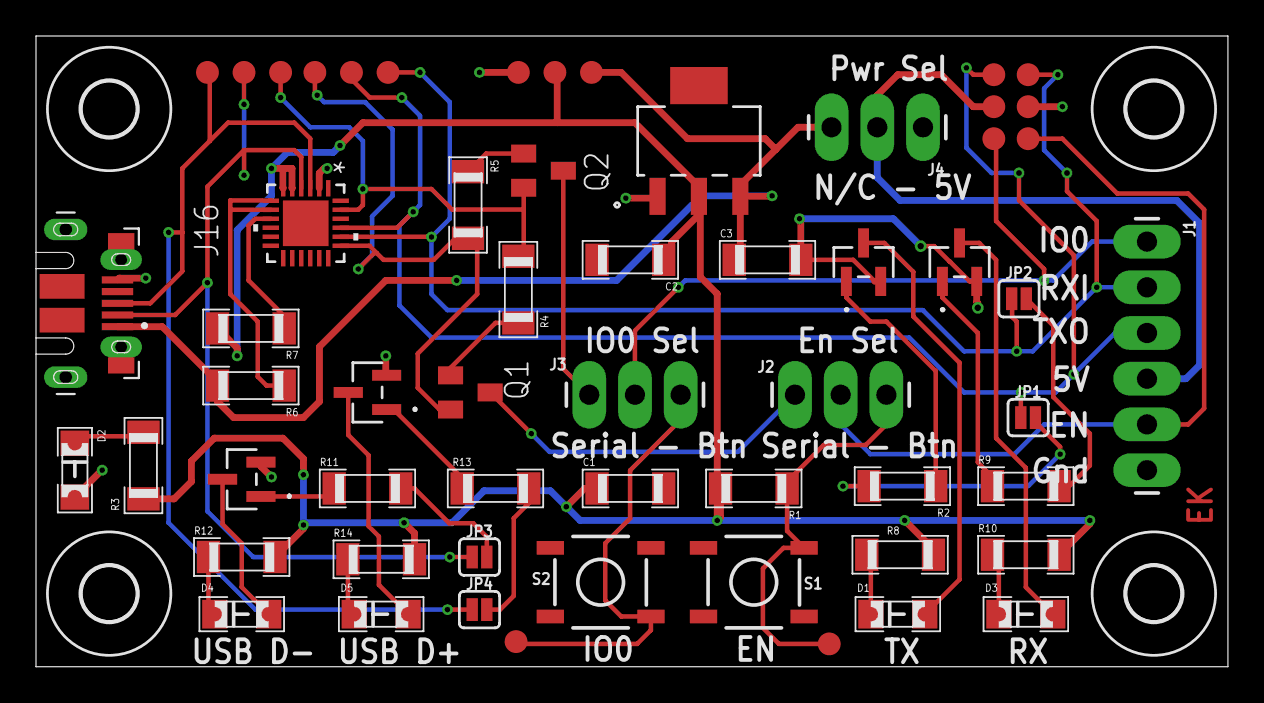
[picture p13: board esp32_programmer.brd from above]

Board: 2 copper layers, 66.2 x 35.0 mm, 62 parts (0 on the bottom side), 38 nets.

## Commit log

2022-12-12 Schematic complete for ESP32-Wroom board
    [esp32-kitchensink.brd, esp32-kitchensink.sch]
2022-12-20 Added DC in and 5V regulator, Started initial pcb layout and routing
    [esp32-kitchensink.brd, esp32-kitchensink.sch]
2022-12-23 Circuit layout complete for mini version
    [kitchensink_esp32_mini.brd, kitchensink_esp32_mini.sch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]
2022-12-23 Schematic and start of circuit board layout for programmer board
    [esp32_programmer.brd, esp32_programmer.sch]
2022-12-24 Programmer board complete
    [esp32_programmer.brd, esp32_programmer.sch, esp32_programmer.step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]
2022-12-28 Archiving previous revisions of board
    [kitchensink_esp32_mini.brd, kitchensink_esp32_mini.sch, kitchensink_esp32_mini_v1.1.brd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]
2022-12-28 Updates to larger kitchen sink files
    [esp32-kitchensink.brd, esp32-kitchensink.sch]
2022-12-28 Kitchen Sink Mini v1.2 board complete
    [kitchensink_mini_esp32_v1.2.brd, kitchensink_mini_esp32_v1.2.sch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]
2022-12-29 Moving previous version to archive
    [esp32_programmer.brd, esp32_programmer.sch, esp32_programmer.step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]
2022-12-29 Programmer v1.1 added
    [esp32_programmer.brd, esp32_programmer.sch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]
2022-12-29 Update changelog for Our Programmer board
2023-01-07 Latest revision of kitchen sink mini v1.2
    [kitchensink_mini_esp32_v1.2.brd, kitchensink_mini_esp32_v1.2.sch]
2023-01-07 Moving previous revision to archive
    [copper_bottom.gbr, copper_top.gbr, drill_1_16.xln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]
2023-01-07 Removing old gerber
    [copper_bottom.gbr, copper_top.gbr, drill_1_16.xln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]
2023-01-07 Moving v1.2 to archive
    [kitchensink_mini_esp32_v1.2.brd, kitchensink_mini_esp32_v1.2.sch]
2023-01-07 Added v1.3
    [kitchensink_mini_esp32_v1.3.brd, kitchensink_mini_esp32_v1.3.sch]

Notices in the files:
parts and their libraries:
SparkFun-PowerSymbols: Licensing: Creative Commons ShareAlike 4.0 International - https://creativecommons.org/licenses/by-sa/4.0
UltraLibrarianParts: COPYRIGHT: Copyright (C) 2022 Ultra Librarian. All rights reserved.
